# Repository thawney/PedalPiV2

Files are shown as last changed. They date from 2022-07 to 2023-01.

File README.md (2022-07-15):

# PedalPi
Pedal Pi Thawney is based off of Pedal-Pi by electrosmash; a lo-fi programmable guitar pedal that works with the Raspberry Pi ZERO Board. My repository contains all of the information needed to create your own board from scratch unlike Pedal Pi who only share effect code.

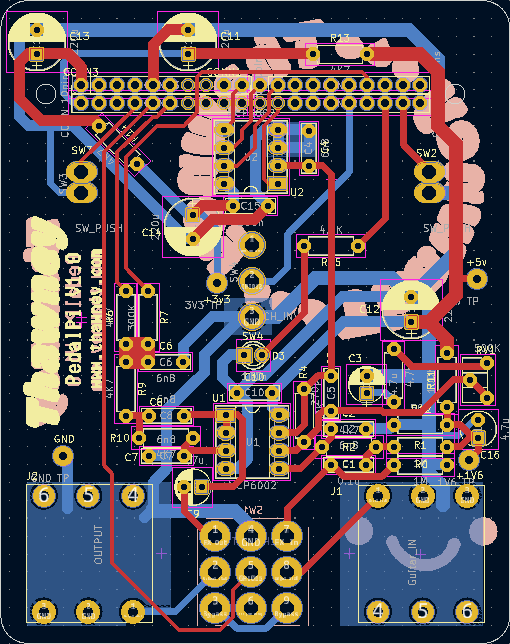
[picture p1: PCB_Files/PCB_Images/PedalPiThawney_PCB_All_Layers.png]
Picture of the Pedal Pi PCB Design


## How Is this Repository different to the original Pedal Pi?

The difference is that my version also has open source PCB files, Protective Case Design files, and anything else needed to make the project yourself (as well as example code of various pugins), unlike electrosmash who claims to be open source but will not share or does not produce certain files (such as PCB files and Protective case designs).

# How Does the Circuit Work?

This  [_hat_](https://www.hifiberry.com/blog/what-is-a-raspberry-pi-hat/) has three parts:

-   The Input Stage:  Amplifies and filters the guitar signal making it ready for the ADC (Analog to Digital Converter). The ADC sends the signal to the PI ZERO using  [SPI communication](https://en.wikipedia.org/wiki/Serial_Peripheral_Interface_Bus). In the forum, the topic "[Using MCP3202 ADC with Raspberry Pi Zero](https://www.electrosmash.com/forum/pedal-pi/212-using-mcp3202-adc-with-raspberry-pi-zero)" gives more details about the ADC-Pi ZERO connection.  
    
-   Pi ZERO:  It takes the digitalized audio waveform from the ADC and does all the Digital Signal Processing (DSP) creating effects (distortion, fuzz, delay, echo, tremolo...). In the forum, the topic "[Basics of Audio DSP in C for Raspberry Pi Zero](https://www.electrosmash.com/forum/pedal-pi/207-basics-of-audio-dsp-in-c-for-rapsberry-pi-zero)" can assist you to learn the basics.
-   The Output Stage:  Once the new digital waveform is created, the Pi Zero creates an analog signal with two PWMs combined, the signal is filtered and prepared to be sent to the next pedal or the guitar amp.  For more info check the topic "[PWM Audio on Raspberry Pi Zero](https://www.electrosmash.com/forum/pedal-pi/210-pwm-audio-on-raspberry-pi-zero)".

Pedal Pi Schematic

- Here is a more detailed photo of just the RaspberryPi Stage.

Raspi explanation schematic
# How to Program it?

The idea is to make it as easy as possible, the examples are programmed in C using the standard  [BCM2835 Libraries](http://www.airspayce.com/mikem/bcm2835/). The Operating System used is  [Raspbian.](https://www.raspberrypi.org/downloads/raspbian/)  All tools and programs are free/open source. In the OFFICIAL forum, there is a topic called  ["How to Start Programming Pedal-Pi"](https://www.electrosmash.com/forum/pedal-pi/202-how-to-start-programming-pedal-pi) with more details (note: this forum is not run or maintained by thawney and is for the original design, all code should still work).

Basic knowledge of Arduino, Linux and C are needed. You can find many Example effects in this repository's Effects folder, the PedalPi legacy effect are the most basic ones currently.

## Need More Support?

Contact Thawney:

- Find all of their social media and othe contact info [here](https://www.thawney.com) or join their [discord](https://discord.com/invite/Eh7VRgu).

ElectroSmash PedalPi Website:

- Whilst some may be very outdated, information on how the project works, old schematics and Learning materials can be found [here](https://www.electrosmash.com/pedal-pi).

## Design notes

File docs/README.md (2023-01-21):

# PedalPi

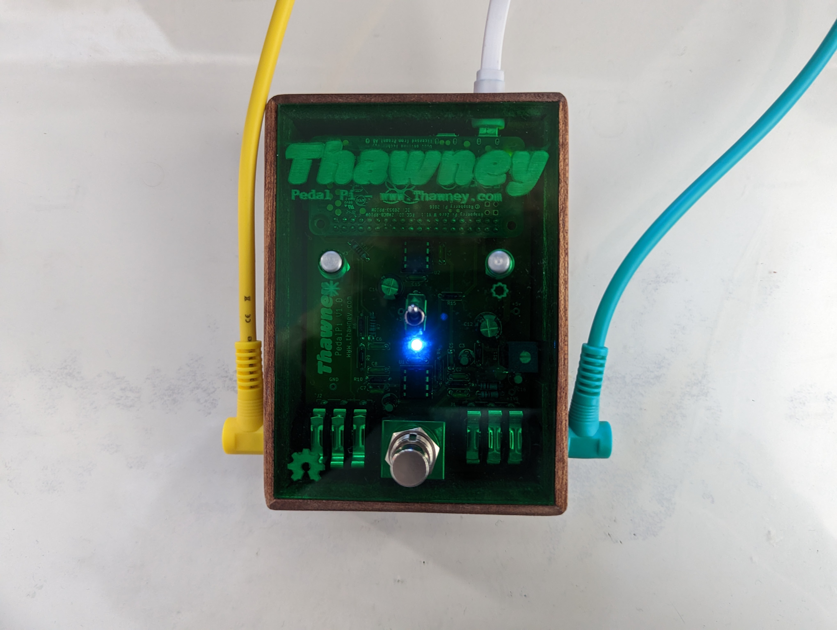
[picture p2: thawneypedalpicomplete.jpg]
Picture of the Pedal Pi PCB Design


Pedal Pi Thawney is based off of Pedal-Pi by electrosmash; a lo-fi programmable guitar pedal that works with the Raspberry Pi ZERO Board. My repository contains all of the information needed to create your own board from scratch unlike Pedal Pi who only share effect code.

[_There is a video demo here_](https://www.youtube.com/watch?v=90KZU-akCmM&ab_channel=Thawney)

## How Is this Repository different to the original Pedal Pi?

The difference is that my version also has open source PCB files, Protective Case Design files, and anything else needed to make the project yourself (as well as example code of various pugins), unlike electrosmash who claims to be open source but will not share or does not produce certain files (such as PCB files and Protective case designs).

# How Does the Circuit Work?

This  [_hat_](https://www.hifiberry.com/blog/what-is-a-raspberry-pi-hat/) has three parts:

-   The Input Stage:  Amplifies and filters the guitar signal making it ready for the ADC (Analog to Digital Converter). The ADC sends the signal to the PI ZERO using  [SPI communication](https://en.wikipedia.org/wiki/Serial_Peripheral_Interface_Bus). In the forum, the topic "[Using MCP3202 ADC with Raspberry Pi Zero](https://www.electrosmash.com/forum/pedal-pi/212-using-mcp3202-adc-with-raspberry-pi-zero)" gives more details about the ADC-Pi ZERO connection.  
    
-   Pi ZERO:  It takes the digitalized audio waveform from the ADC and does all the Digital Signal Processing (DSP) creating effects (distortion, fuzz, delay, echo, tremolo...). In the forum, the topic "[Basics of Audio DSP in C for Raspberry Pi Zero](https://www.electrosmash.com/forum/pedal-pi/207-basics-of-audio-dsp-in-c-for-rapsberry-pi-zero)" can assist you to learn the basics.
-   The Output Stage:  Once the new digital waveform is created, the Pi Zero creates an analog signal with two PWMs combined, the signal is filtered and prepared to be sent to the next pedal or the guitar amp.  For more info check the topic "[PWM Audio on Raspberry Pi Zero](https://www.electrosmash.com/forum/pedal-pi/210-pwm-audio-on-raspberry-pi-zero)".

Pedal Pi Schematic

- Here is a more detailed photo of just the RaspberryPi Stage.

Raspi explanation schematic
# How to Program it?

The idea is to make it as easy as possible, the examples are programmed in C using the standard  [BCM2835 Libraries](http://www.airspayce.com/mikem/bcm2835/). The Operating System used is  [Raspbian.](https://www.raspberrypi.org/downloads/raspbian/)  All tools and programs are free/open source. In the OFFICIAL forum, there is a topic called  ["How to Start Programming Pedal-Pi"](https://www.electrosmash.com/forum/pedal-pi/202-how-to-start-programming-pedal-pi) with more details (note: this forum is not run or maintained by thawney and is for the original design, all code should still work).

Basic knowledge of Arduino, Linux and C are needed. You can find many Example effects in this repository's Effects folder, the PedalPi legacy effect are the most basic ones currently.

## Need More Support?

Contact Thawney:

- Find all of their social media and othe contact info [here](https://www.thawney.com) or join their [discord](https://discord.com/invite/Eh7VRgu).

ElectroSmash PedalPi Website:

- Whilst some may be very outdated, information on how the project works, old schematics and Learning materials can be found [here](https://www.electrosmash.com/pedal-pi).

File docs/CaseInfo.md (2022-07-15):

# Info On The Cases.

Currently There aren't any designs for cases as I haven't finished building my PCB and I am yet to get my hands on a Raspberry Pi Zero. Because of this I need to make a model of the project to get accurate measurements for cases. (Alternatively if someone wants to make a cad model of the PedalPi that would be amazing)

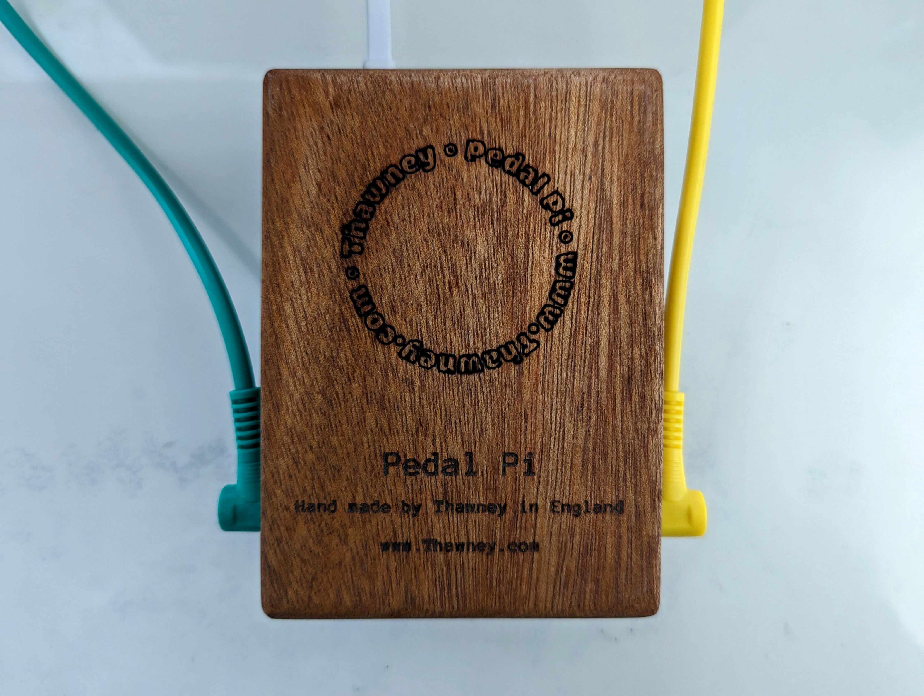
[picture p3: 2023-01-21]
thawneypedalpicompleteback.jpg

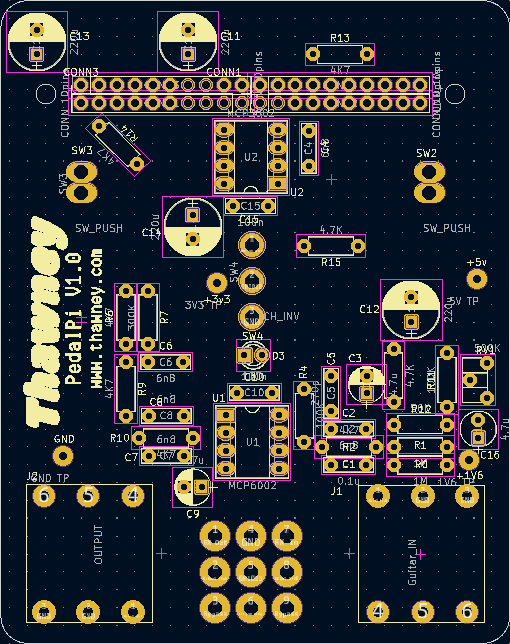
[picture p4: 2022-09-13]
PCB_Files/PCB_Images/PedalPiThawney_PCB_Front_layers.png

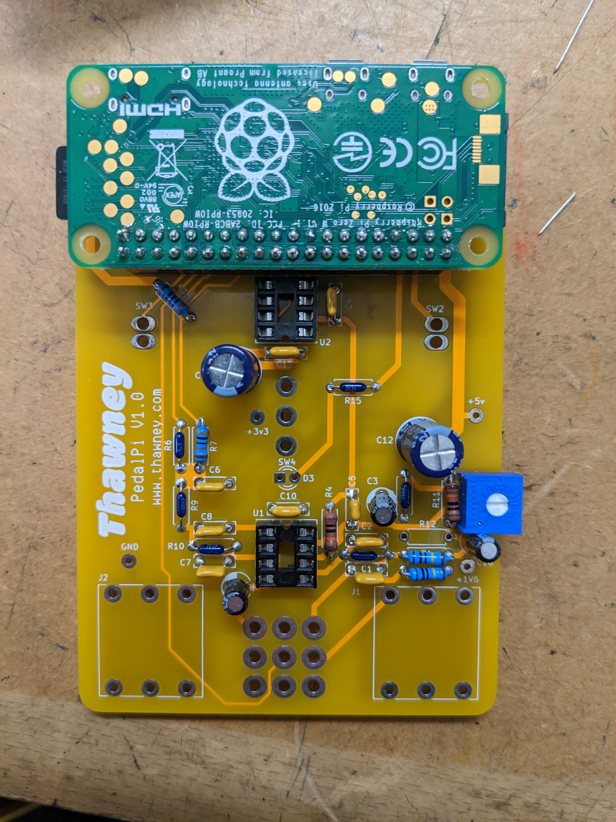
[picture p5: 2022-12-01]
PCB_Files/PCB_Images/PedalPiThawney_PCB_Wip.jpg

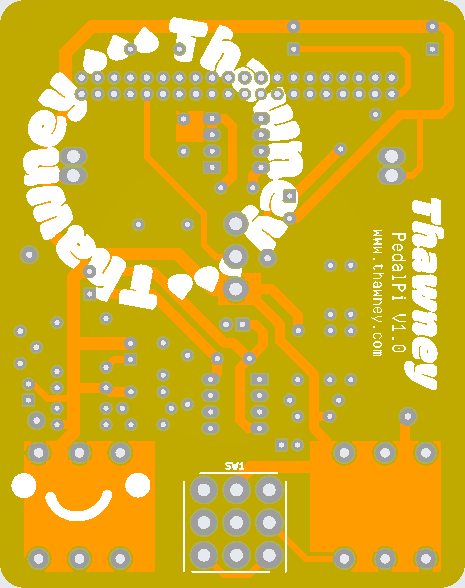
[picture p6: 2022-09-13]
PCB_Files/PCB_Images/PedalPiThawney_PCB_Back.png

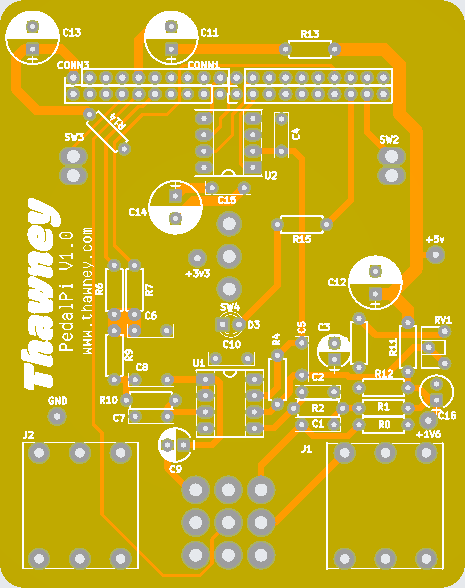
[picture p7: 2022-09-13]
PCB_Files/PCB_Images/PedalPiThawney_PCB_Front.png

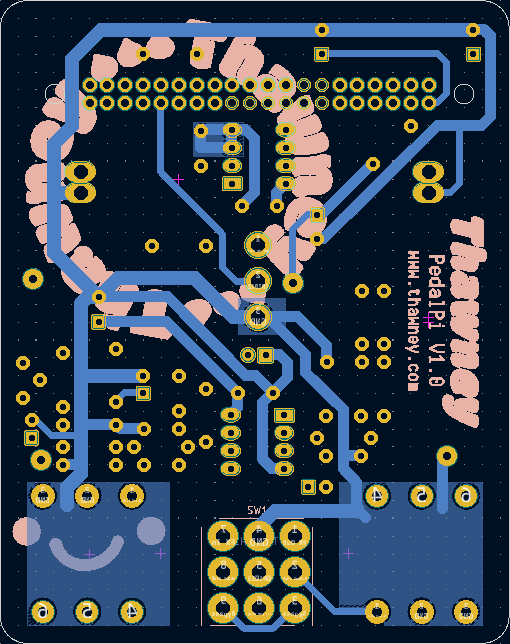
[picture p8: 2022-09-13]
PCB_Files/PCB_Images/PedalPiThawney_PCB_Back_layers.png

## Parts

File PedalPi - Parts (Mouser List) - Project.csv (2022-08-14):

NOTE!!! YOU WILL ALSO NEED TO SUPPLY PINS FOR YOUR PI ZERO AS WELL AS A PI ZERO. SOME PARTS HAVE CHANGED FROM THE OG PEDALPI LIST AS THEY ARE DISCONTINUED, I CANNOT YET PROMISE THAT THESE REPLACEMENTS WORK
PEDALPI
Mouser No | Mfr. No | Manufacturer | Customer No | Description | RoHS | Lifecycle | Order Qty. | Price (GBP) | Ext.: (GBP)
581-SR211C682MARTR1 | SR211C682MARTR1 | Kyocera AVX |  | Multilayer Ceramic Capacitors MLCC - Leaded 100V 6800 pF X7R 20% RoHS Long Leads |  |  | 5 | £0.462 | £2.31
581-SR211C104KARTR1 | SR211C104KARTR1 | Kyocera AVX |  | Multilayer Ceramic Capacitors MLCC - Leaded 100V 0.1uF X7R RoHS Long Leads 10% |  |  | 3 | £0.277 | £0.83
594-K271J15C0GF5TL2 | K271J15C0GF5TL2 | Vishay |  | Multilayer Ceramic Capacitors MLCC - Leaded 270pF 50V 5% C0G 2.5mm LS | RoHS Compliant |  | 1 | £0.294 | £0.29
667-ECE-A1EKA4R7 | ECE-A1EKA4R7 | Panasonic |  | Aluminium Electrolytic Capacitors - Radial Leaded 4.7UF 25V MINI ALUM ELECT (KA) | RoHS Compliant |  | 3 | £0.286 | £0.86
75-515D227M016BB6AE3 | 515D227M016BB6AE3 | Vishay |  | Aluminium Electrolytic Capacitors - Radial Leaded 220uF 16volts 20% | RoHS Compliant |  | 4 | £0.622 | £2.49
594-HVR2500001004FR5 | HVR2500001004FR500 | Vishay |  | Metal Film Resistors - Through Hole 1/4watt 1Mohms 1% | RoHS Compliant |  | 2 | £0.361 | £0.72
71-CMF50-F-4.7K/R | CMF504K7000FKR6 | Vishay |  | Metal Film Resistors - Through Hole 1/4watt 4.7Kohms 1% | No |  | 6 | £0.622 | £3.73
71-CCF55100KFKE36 | CCF55100KFKE36 | Vishay |  | Metal Film Resistors - Through Hole 1/4watt 100Kohms 1% Rated to 1/2watt | RoHS Compliant |  | 2 | £0.176 | £0.35
603-MFR-25FRF52-300K | MFR-25FRF52-300K | YAGEO |  | Metal Film Resistors - Through Hole 300K OHM 1/4W 1% | RoHS Compliant |  | 1 | £0.101 | £0.10
603-MFR-25FRF52-300R | MFR-25FRF52-300R | YAGEO |  | Metal Film Resistors - Through Hole 300 OHM 1/4W 1% | RoHS Compliant |  | 2 | £0.101 | £0.20
531-PTC10V-500K | PTC10LV10-504A2020 | Amphenol |  | Trimmer Resistors - Through Hole 500Kohms 10mm Rnd | RoHS Compliant By Exemption |  | 1 | £1.41 | £1.41
593-LTH3MM12VFR4600 | LTH3MM12VFR4600 | VCC |  | Standard LEDs - Through Hole 3mm Thru Hole LED 467nm for 12VDC | RoHS Compliant |  | 1 | £1.02 | £1.02
579-MCP3202-CI/P | MCP3202-CI/P | Microchip |  | Analog to Digital Converters - ADC 12-bit SPI Dual Chl | RoHS Compliant |  | 1 | £3.05 | £3.05
571-1-2199298-2 | 1-2199298-2 | TE Connectivity |  | IC & Component Sockets 8P DIP SKT 300 CL LADDER | Not Applicable |  | 2 | £0.437 | £0.87
107-SF17020F-32-21RL | SF17020F-0302-21R-L-015 | Alpha (Taiwan) |  | Pushbutton Switches 3PDT STOMP/FOOT SW LATCHING 1A9VDC 9PIN | RoHS Compliant |  | 1 | £6.54 | £6.54
612-100-A1111 | 100SP1T1B1M1QEH | E-Switch |  | Toggle Switches SPDT ON-ON Panel MNT | RoHS Compliant |  | 1 | £2.37 | £2.37
633-FB15ANEP2-FA | FB15ANEP2-FA | NKK Switches |  | Pushbutton Switches SPST OFF-(ON) 500mA .201 BLK CAP TUR/PC | RoHS Compliant By Exemption |  | 2 | £3.31 | £6.62
550-22302 | NMJ6HCD2 | Neutrik |  | Phone Connectors STEREO CHROME NOSE | RoHS Compliant |  | 2 | £1.47 | £2.94
71-RN65E5002B | RN65E5002BB14 | Vishay |  | Metal Film Resistors - Through Hole 1/4watt 50Kohms .1% 25ppm | No |  | 1 | £1.96 | £1.96
579-MCP6002-E/P | MCP6002-E/P | Microchip |  | Operational Amplifiers - Op Amps Dual 1.8V 1MHz | RoHS Compliant |  | 1 | £0.445 | £0.45

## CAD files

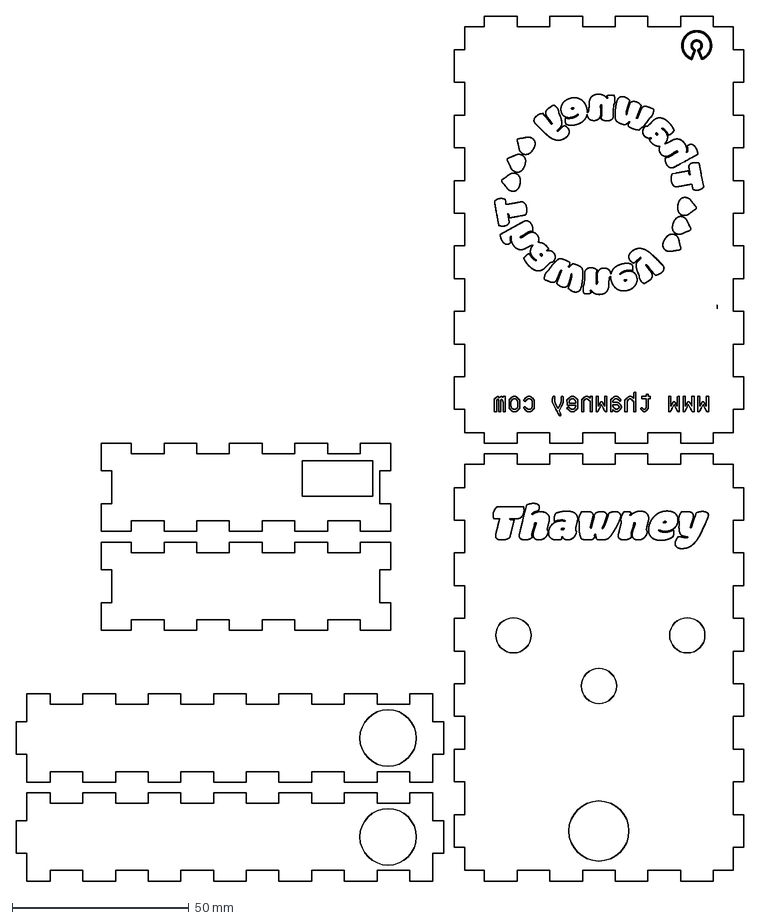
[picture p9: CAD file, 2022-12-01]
Cases/Laser Cut/Finger Joint Box/Pedal Pi Laser Cuttable Box.dxf
206.0 x 245.0 mm

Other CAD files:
Cases/Laser Cut/Finger Joint Box/Pedal Pi Laser Cuttable Box.f3d

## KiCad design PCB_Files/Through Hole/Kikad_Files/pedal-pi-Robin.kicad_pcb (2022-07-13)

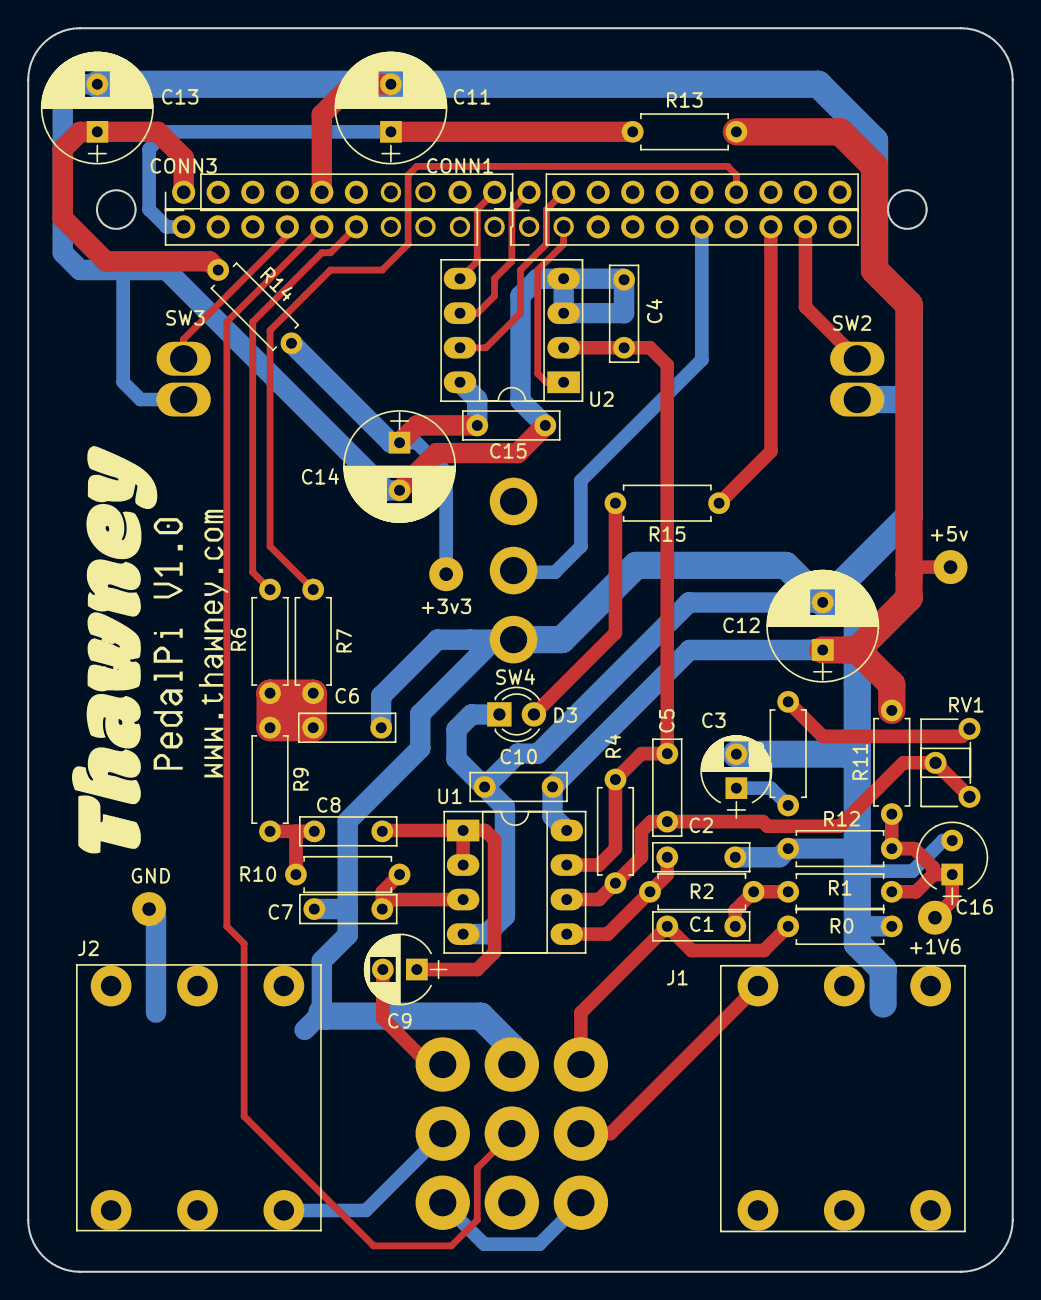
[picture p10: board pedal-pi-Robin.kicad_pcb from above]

Board: 2 copper layers, 72.4 x 91.4 mm, 48 parts (1 on the bottom side), 33 nets.

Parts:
+1V6: 1V6 TP; SolderWirePad_single_1mmDrill
+3v3: 3V3 TP; SolderWirePad_single_1mmDrill
+5v: 5V TP; SolderWirePad_single_1mmDrill
C1: 0.1u; C_Rect_L7.0mm_W2.0mm_P5.00mm
C2, C4, C6, C7, C8: 6n8; C_Rect_L7.0mm_W2.0mm_P5.00mm
C3, C9: 4.7u; CP_Radial_D5.0mm_P2.50mm
C5: 270p; C_Rect_L7.0mm_W2.0mm_P5.00mm
C10, C15: 100n; C_Rect_L7.0mm_W2.0mm_P5.00mm
C11, C12, C13, C14: 220u; CP_Radial_D8.0mm_P3.50mm
C16: 4.7u; CP_Radial_Tantal_D5.0mm_P2.50mm
CONN1, CONN2, CONN3, CONN4: CONN_10pins; Pin_Header_Straight_1x10_Pitch2.54mm
D3: LED; LED_D3.0mm
GND: GND TP; SolderWirePad_single_1mmDrill
J1: Guitar_IN; StereoJack-NYS216_2
J2: OUTPUT; StereoJack-NYS216_2
R0, R1: 1M; R_Axial_DIN0207_L6.3mm_D2.5mm_P7.62mm_Horizontal
R2, R6, R9, R10, R13, R14: 4K7; R_Axial_DIN0207_L6.3mm_D2.5mm_P7.62mm_Horizontal
R3, R15: 4.7K; R_Axial_DIN0207_L6.3mm_D2.5mm_P7.62mm_Horizontal
R4, R11: 100K; R_Axial_DIN0207_L6.3mm_D2.5mm_P7.62mm_Horizontal
R7: 300K; R_Axial_DIN0207_L6.3mm_D2.5mm_P7.62mm_Horizontal
R12: 50K; R_Axial_DIN0207_L6.3mm_D2.5mm_P7.62mm_Horizontal
RV1: 500K; Potentiometer_Trimmer_ACP_CA6h_Vertical
SW1: SWITCH_3PDT; 3PDTswitch
SW2, SW3: SW_PUSH; Switch2
SW4: SWITCH_INV; Switch
U1: MCP6002; DIP-8_W7.62mm_Socket_LongPads
U2: MCP3002; DIP-8_W7.62mm_Socket_LongPads

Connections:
+1V5: +1V6.1, C16.1, R1.2, R11.2, R12.1
+3.3VADC: +3v3.1, C14.1, C15.1, R14.2, U2.8
+3V3: C13.1, CONN3.1, R14.1
+5V: C11.1, CONN1.10, R13.1
+5VA: +5v.1, C10.1, C12.1, R11.1, R13.2, U1.8
/ADC0: C4.1, C5.1, R4.2, U1.7, U2.2
/Bypass: SW1.3, SW1.9
/FX In: C1.1, R0.1, SW1.7
/FX Out: C9.2, SW1.1
/GPIO12: CONN2.6, SW4.2
/GPIO14: CONN1.7, SW3.1
/GPIO15: CONN1.6, SW1.5
/GPIO16: CONN2.8, R15.1
/GPIO20: CONN2.9, SW2.1
/Input Jack: J1.1, SW1.8
/Output JAck: J2.1, SW1.2
/PWM0: CONN1.5, R6.1
/PWM1: CONN4.7, R7.1
/SPI_CLK: CONN4.2, U2.7
/SPI_CS: CONN2.2, U2.1
/SPI_MISO: CONN4.1, U2.6
/SPI_MOSI: CONN3.10, U2.5
GND: C2.2, C3.2, C4.2, C6.2, C7.2, C10.2, C11.2, C12.2, C13.2, C14.2, C15.2, C16.2, CONN3.5, D3.1, GND.1, J1.2, J1.3, J2.2, J2.3, R0.2, R12.2, SW1.4, SW2.2, SW3.2, SW4.3, U1.4, U2.3, U2.4
unnamed: C1.2, R1.1, R2.1
unnamed: C2.1, R2.2, U1.5
unnamed: C3.1, R3.1
unnamed: C5.2, R4.1, RV1.1, RV1.2, U1.6
unnamed: C6.1, R6.2, R7.2, R9.1
unnamed: C7.1, R10.2, U1.3
unnamed: C8.1, C9.1, U1.1, U1.2
unnamed: C8.2, R9.2, R10.1
unnamed: D3.2, R15.2
unnamed: R3.2, RV1.3

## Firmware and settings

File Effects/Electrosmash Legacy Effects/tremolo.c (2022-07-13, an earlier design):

// CC-by-www.Electrosmash.com Pedal-Pi open-source project.
// tremolo audio effect.

#include <bcm2835.h>
#include <stdio.h>

// Define Input Pins
#define PUSH1 			RPI_GPIO_P1_08  	//GPIO14
#define PUSH2 			RPI_V2_GPIO_P1_38  	//GPIO20 
#define TOGGLE_SWITCH 	RPI_V2_GPIO_P1_32 	//GPIO12
#define FOOT_SWITCH 	RPI_GPIO_P1_10 		//GPIO15
#define LED   			RPI_V2_GPIO_P1_36 	//GPIO16

//To create the sinewave samples I have used this website:
//http://www.daycounter.com/Calculators/Sine-Generator-Calculator.phtml 
//the generated signal is 1000 points and 4095 max. amplitude

uint32_t waveform[]= {0x800,0x80c,0x819,0x826,0x833,0x840,0x84d,0x85a,0x866,0x873,0x880,0x88d,0x89a,0x8a7,0x8b3,0x8c0,
0x8cd,0x8da,0x8e7,0x8f3,0x900,0x90d,0x91a,0x926,0x933,0x940,0x94c,0x959,0x966,0x973,0x97f,0x98c,
0x998,0x9a5,0x9b2,0x9be,0x9cb,0x9d7,0x9e4,0x9f0,0x9fd,0xa09,0xa16,0xa22,0xa2e,0xa3b,0xa47,0xa53,
0xa60,0xa6c,0xa78,0xa84,0xa91,0xa9d,0xaa9,0xab5,0xac1,0xacd,0xad9,0xae5,0xaf1,0xafd,0xb09,0xb15,
0xb21,0xb2d,0xb38,0xb44,0xb50,0xb5c,0xb67,0xb73,0xb7e,0xb8a,0xb96,0xba1,0xbac,0xbb8,0xbc3,0xbcf,
0xbda,0xbe5,0xbf0,0xbfc,0xc07,0xc12,0xc1d,0xc28,0xc33,0xc3e,0xc49,0xc53,0xc5e,0xc69,0xc74,0xc7e,
0xc89,0xc94,0xc9e,0xca9,0xcb3,0xcbd,0xcc8,0xcd2,0xcdc,0xce6,0xcf1,0xcfb,0xd05,0xd0f,0xd19,0xd23,
0xd2c,0xd36,0xd40,0xd4a,0xd53,0xd5d,0xd66,0xd70,0xd79,0xd82,0xd8c,0xd95,0xd9e,0xda7,0xdb0,0xdb9,
0xdc2,0xdcb,0xdd4,0xddd,0xde6,0xdee,0xdf7,0xdff,0xe08,0xe10,0xe19,0xe21,0xe29,0xe31,0xe39,0xe41,
0xe49,0xe51,0xe59,0xe61,0xe69,0xe70,0xe78,0xe7f,0xe87,0xe8e,0xe96,0xe9d,0xea4,0xeab,0xeb2,0xeb9,
0xec0,0xec7,0xece,0xed5,0xedb,0xee2,0xee8,0xeef,0xef5,0xefc,0xf02,0xf08,0xf0e,0xf14,0xf1a,0xf20,
0xf26,0xf2b,0xf31,0xf37,0xf3c,0xf42,0xf47,0xf4c,0xf51,0xf57,0xf5c,0xf61,0xf66,0xf6a,0xf6f,0xf74,
0xf79,0xf7d,0xf82,0xf86,0xf8a,0xf8f,0xf93,0xf97,0xf9b,0xf9f,0xfa3,0xfa6,0xfaa,0xfae,0xfb1,0xfb5,
0xfb8,0xfbb,0xfbf,0xfc2,0xfc5,0xfc8,0xfcb,0xfce,0xfd0,0xfd3,0xfd6,0xfd8,0xfdb,0xfdd,0xfdf,0xfe2,
0xfe4,0xfe6,0xfe8,0xfea,0xfeb,0xfed,0xfef,0xff0,0xff2,0xff3,0xff5,0xff6,0xff7,0xff8,0xff9,0xffa,
0xffb,0xffc,0xffc,0xffd,0xffe,0xffe,0xffe,0xfff,0xfff,0xfff,0xfff,0xfff,0xfff,0xfff,0xffe,0xffe,
0xffe,0xffd,0xffc,0xffc,0xffb,0xffa,0xff9,0xff8,0xff7,0xff6,0xff5,0xff3,0xff2,0xff0,0xfef,0xfed,
0xfeb,0xfea,0xfe8,0xfe6,0xfe4,0xfe2,0xfdf,0xfdd,0xfdb,0xfd8,0xfd6,0xfd3,0xfd0,0xfce,0xfcb,0xfc8,
0xfc5,0xfc2,0xfbf,0xfbb,0xfb8,0xfb5,0xfb1,0xfae,0xfaa,0xfa6,0xfa3,0xf9f,0xf9b,0xf97,0xf93,0xf8f,
0xf8a,0xf86,0xf82,0xf7d,0xf79,0xf74,0xf6f,0xf6a,0xf66,0xf61,0xf5c,0xf57,0xf51,0xf4c,0xf47,0xf42,
0xf3c,0xf37,0xf31,0xf2b,0xf26,0xf20,0xf1a,0xf14,0xf0e,0xf08,0xf02,0xefc,0xef5,0xeef,0xee8,0xee2,
0xedb,0xed5,0xece,0xec7,0xec0,0xeb9,0xeb2,0xeab,0xea4,0xe9d,0xe96,0xe8e,0xe87,0xe7f,0xe78,0xe70,
0xe69,0xe61,0xe59,0xe51,0xe49,0xe41,0xe39,0xe31,0xe29,0xe21,0xe19,0xe10,0xe08,0xdff,0xdf7,0xdee,
0xde6,0xddd,0xdd4,0xdcb,0xdc2,0xdb9,0xdb0,0xda7,0xd9e,0xd95,0xd8c,0xd82,0xd79,0xd70,0xd66,0xd5d,
0xd53,0xd4a,0xd40,0xd36,0xd2c,0xd23,0xd19,0xd0f,0xd05,0xcfb,0xcf1,0xce6,0xcdc,0xcd2,0xcc8,0xcbd,
0xcb3,0xca9,0xc9e,0xc94,0xc89,0xc7e,0xc74,0xc69,0xc5e,0xc53,0xc49,0xc3e,0xc33,0xc28,0xc1d,0xc12,
0xc07,0xbfc,0xbf0,0xbe5,0xbda,0xbcf,0xbc3,0xbb8,0xbac,0xba1,0xb96,0xb8a,0xb7e,0xb73,0xb67,0xb5c,
0xb50,0xb44,0xb38,0xb2d,0xb21,0xb15,0xb09,0xafd,0xaf1,0xae5,0xad9,0xacd,0xac1,0xab5,0xaa9,0xa9d,
0xa91,0xa84,0xa78,0xa6c,0xa60,0xa53,0xa47,0xa3b,0xa2e,0xa22,0xa16,0xa09,0x9fd,0x9f0,0x9e4,0x9d7,
0x9cb,0x9be,0x9b2,0x9a5,0x998,0x98c,0x97f,0x973,0x966,0x959,0x94c,0x940,0x933,0x926,0x91a,0x90d,
0x900,0x8f3,0x8e7,0x8da,0x8cd,0x8c0,0x8b3,0x8a7,0x89a,0x88d,0x880,0x873,0x866,0x85a,0x84d,0x840,
0x833,0x826,0x819,0x80c,0x800,0x7f3,0x7e6,0x7d9,0x7cc,0x7bf,0x7b2,0x7a5,0x799,0x78c,0x77f,0x772,
0x765,0x758,0x74c,0x73f,0x732,0x725,0x718,0x70c,0x6ff,0x6f2,0x6e5,0x6d9,0x6cc,0x6bf,0x6b3,0x6a6,
0x699,0x68c,0x680,0x673,0x667,0x65a,0x64d,0x641,0x634,0x628,0x61b,0x60f,0x602,0x5f6,0x5e9,0x5dd,
0x5d1,0x5c4,0x5b8,0x5ac,0x59f,0x593,0x587,0x57b,0x56e,0x562,0x556,0x54a,0x53e,0x532,0x526,0x51a,
0x50e,0x502,0x4f6,0x4ea,0x4de,0x4d2,0x4c7,0x4bb,0x4af,0x4a3,0x498,0x48c,0x481,0x475,0x469,0x45e,
0x453,0x447,0x43c,0x430,0x425,0x41a,0x40f,0x403,0x3f8,0x3ed,0x3e2,0x3d7,0x3cc,0x3c1,0x3b6,0x3ac,
0x3a1,0x396,0x38b,0x381,0x376,0x36b,0x361,0x356,0x34c,0x342,0x337,0x32d,0x323,0x319,0x30e,0x304,
0x2fa,0x2f0,0x2e6,0x2dc,0x2d3,0x2c9,0x2bf,0x2b5,0x2ac,0x2a2,0x299,0x28f,0x286,0x27d,0x273,0x26a,
0x261,0x258,0x24f,0x246,0x23d,0x234,0x22b,0x222,0x219,0x211,0x208,0x200,0x1f7,0x1ef,0x1e6,0x1de,
0x1d6,0x1ce,0x1c6,0x1be,0x1b6,0x1ae,0x1a6,0x19e,0x196,0x18f,0x187,0x180,0x178,0x171,0x169,0x162,
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


uint32_t read_timer=0;
uint32_t divider=0;
uint32_t sample=0;
uint32_t input_signal=0;
uint32_t output_signal=0;
uint32_t speed=1;
uint32_t max_count=25;
uint8_t FOOT_SWITCH_val;
uint8_t TOGGLE_SWITCH_val;
uint8_t PUSH1_val;
uint8_t PUSH2_val;

int main(int argc, char **argv)
{
    // Start the BCM2835 Library to access GPIO.
    if (!bcm2835_init())
    { printf("bcm2835_init failed. Are you running as root??\n");
      return 1;}
	// Start the SPI BUS.
	if (!bcm2835_spi_begin())
    {printf("bcm2835_spi_begin failed. Are you running as root??\n");
      return 1;}
	
	//define PWM	
    bcm2835_gpio_fsel(18,BCM2835_GPIO_FSEL_ALT5 ); //PWM0 signal on GPIO18    
    bcm2835_gpio_fsel(13,BCM2835_GPIO_FSEL_ALT0 ); //PWM1 signal on GPIO13    
	bcm2835_pwm_set_clock(2); // Max clk frequency (19.2MHz/2 = 9.6MHz)
    bcm2835_pwm_set_mode(0,1 , 1); //channel 0, markspace mode, PWM enabled. 
	bcm2835_pwm_set_range(0,64);   //channel 0, 64 is max range (6bits): 9.6MHz/64=150KHz switching PWM freq.
    bcm2835_pwm_set_mode(1, 1, 1); //channel 1, markspace mode, PWM enabled.
	bcm2835_pwm_set_range(1,64);   //channel 0, 64 is max range (6bits): 9.6MHz/64=150KHz switching PWM freq.
	
	//define SPI bus configuration
    bcm2835_spi_setBitOrder(BCM2835_SPI_BIT_ORDER_MSBFIRST);      // The default
    bcm2835_spi_setDataMode(BCM2835_SPI_MODE0);                   // The default
    bcm2835_spi_setClockDivider(BCM2835_SPI_CLOCK_DIVIDER_64); 	  // 4MHz clock with _64 
    bcm2835_spi_chipSelect(BCM2835_SPI_CS0);                      // The default
    bcm2835_spi_setChipSelectPolarity(BCM2835_SPI_CS0, LOW);      // the default

   	uint8_t mosi[10] = { 0x01, 0x00, 0x00 }; //12 bit ADC read 0x08 ch0, - 0c for ch1 
	uint8_t miso[10] = { 0 };
	
    //Define GPIO pins configuration
    bcm2835_gpio_fsel(PUSH1, BCM2835_GPIO_FSEL_INPT); 			//PUSH1 button as input
	bcm2835_gpio_fsel(PUSH2, BCM2835_GPIO_FSEL_INPT); 			//PUSH2 button as input
	bcm2835_gpio_fsel(TOGGLE_SWITCH, BCM2835_GPIO_FSEL_INPT);	//TOGGLE_SWITCH as input
	bcm2835_gpio_fsel(FOOT_SWITCH, BCM2835_GPIO_FSEL_INPT); 	//FOOT_SWITCH as input
	bcm2835_gpio_fsel(LED, BCM2835_GPIO_FSEL_OUTP);				//LED as output
	
    bcm2835_gpio_set_pud(PUSH1, BCM2835_GPIO_PUD_UP);           //PUSH1 pull-up enabled   
	bcm2835_gpio_set_pud(PUSH2, BCM2835_GPIO_PUD_UP);           //PUSH2 pull-up enabled 
	bcm2835_gpio_set_pud(TOGGLE_SWITCH, BCM2835_GPIO_PUD_UP);   //TOGGLE_SWITCH pull-up enabled 
	bcm2835_gpio_set_pud(FOOT_SWITCH, BCM2835_GPIO_PUD_UP);     //FOOT_SWITCH pull-up enabled 
	
	while(1) //Main Loop
	{
	//read 12 bits ADC
    bcm2835_spi_transfernb(mosi, miso, 3);
    input_signal = miso[2] + ((miso[1] & 0x0F) << 8); 

	//Read the PUSH buttons every 50000 times (0.25s) to save resources.
	read_timer++;
	if (read_timer==50000)
	{
	read_timer=0;
	uint8_t PUSH1_val = bcm2835_gpio_lev(PUSH1);
	uint8_t PUSH2_val = bcm2835_gpio_lev(PUSH2);
    TOGGLE_SWITCH_val = bcm2835_gpio_lev(TOGGLE_SWITCH);
	uint8_t FOOT_SWITCH_val = bcm2835_gpio_lev(FOOT_SWITCH);
	//light the effect when the footswitch is activated.
	bcm2835_gpio_write(LED,!FOOT_SWITCH_val); 
	
	//update speed when the PUSH1 or 2 buttons are pushed.
	if (PUSH2_val==0)
		{ bcm2835_delay(100); //100ms delay for buttons debouncing
         if (max_count<50) max_count=max_count++;
		}
		else if (PUSH1_val==0) 
			{bcm2835_delay(100); //100ms delay for buttons debouncing.

			if (max_count>1) max_count=max_count--;
			}
	}

	//**** TREMOLO EFFECT ***///
	//the output_signal value is modulated (using a similar operation as in the booster effect) with a 
	//sinusoidal waveform stored in waveform[sample]

	divider++;
  if (divider==max_count){ divider=0; sample++;}
  
  if(sample==999)sample=1;
 output_signal= (int)(((float)input_signal) * ((float)waveform[sample]/4095.0));
		
	//generate output PWM signal 6 bits
    bcm2835_pwm_set_data(1,output_signal & 0x3F);
    bcm2835_pwm_set_data(0,output_signal >> 6);
    }
	
	//close all and exit
	bcm2835_spi_end();
    bcm2835_close();
    return 0;
}

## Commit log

2022-07-13 Added V1 PCB Files
    Includes images of the pcb design, Kikad files to edit your own version and premade gerber files to produce your own pcb
    [PedalPi-B_Cu.gbr, PedalPi-B_Mask.gbr, PedalPi-B_Paste.gbr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]
2022-07-14 Create Electronics_Components_List.csv
    Components needed for V1.0 Some Components may be different to the original ElectroSmash list as their components list contains discontinued parts.
    [Electronics_Components_List.csv]
2022-07-15 Added Folder For Cases
    Added case folder and also made explanation Doc
2022-07-23 added stuff for SMD pcb
    [PedalPi-B_Cu.gbr, PedalPi-B_Mask.gbr, PedalPi-B_Paste.gbr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]
2022-08-14 Updated Components List
    [Electronics_Components_List.csv, PedalPi - Parts (Mouser List) - Project.csv]
2022-10-25 added image of wip PCB
2022-12-01 Added The First Case - Laser Cuttable
    It is a basic case for the pedal pi to be cut on 3mm Material. F3d file on fusion 360 to edit source or dxf for maximum compatibility.
    [Pedal Pi Laser Cuttable Box.dxf, Pedal Pi Laser Cuttable Box.f3d]
